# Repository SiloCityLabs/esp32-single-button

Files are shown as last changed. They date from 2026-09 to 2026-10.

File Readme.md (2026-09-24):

# ESP32 Single Button — battery keyfob (XIAO C3 / C6)

ESPHome firmware for a **single-button**, battery-powered remote on the same core circuit as [ESPFob](../espfob): one switch, WS2812B RGB with MOSFET power gating, and switched battery divider for low idle drain.

## Pin map (D silkscreen)

| D pin | Function | Notes |
| ----- | --- | --- |
| D0 | Battery sense  | 1:2 divider — multiply by 2 in YAML  |
| D1 | Button (SW1) | Deep-sleep wake (RTC / LP on C3 / C6) |
| D6 | RGB data | WS2812B |
| D9 | RGB power | HIGH = LED powered |
| D10 | Divider power  | HIGH = battery measurement enabled |

Button is active **low** (external 10k pull-up). On boot and each press, firmware briefly pulses the RGB LED, samples battery voltage, stays awake ~5s after each press (configurable via `awake_after_button_ms`), then deep sleeps until the next press.

## Files

| File | Target |
| --- | --- |
| `esphome-common.yaml` | Shared hardware / logic |
| `esphome-c6.yaml`  | Seeed XIAO **ESP32-C6** |
| `esphome-c3.yaml`  | Seeed XIAO **ESP32-C3** |

## Build and flash

```bash
make setup
make config-c6
make flash-c6
```

Factory images after `make build`: `firmware-c6.bin`, `firmware-c3.bin`.

Provisioning: Improv (BLE + serial) and captive portal fallback, same pattern as ESPFob.

## Home Assistant

Add the device via ESPHome Dashboard (open `esphome-c6.yaml` or clone this repo). Automate on the **Button** binary sensor entity.

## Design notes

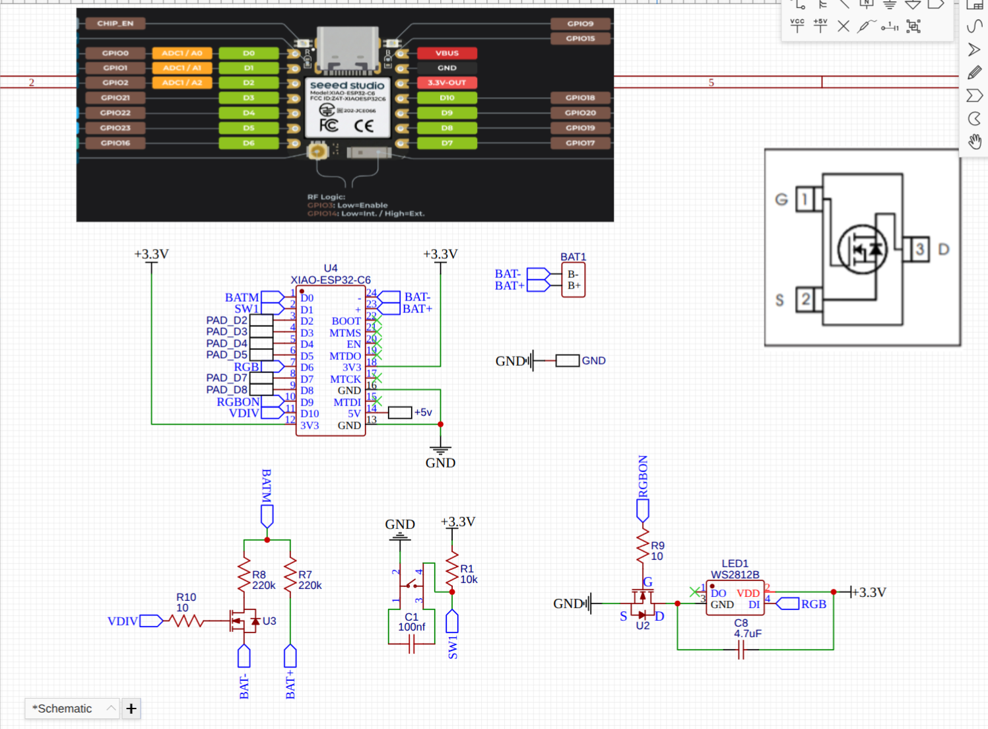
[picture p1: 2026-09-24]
images/schematic-rev1.png

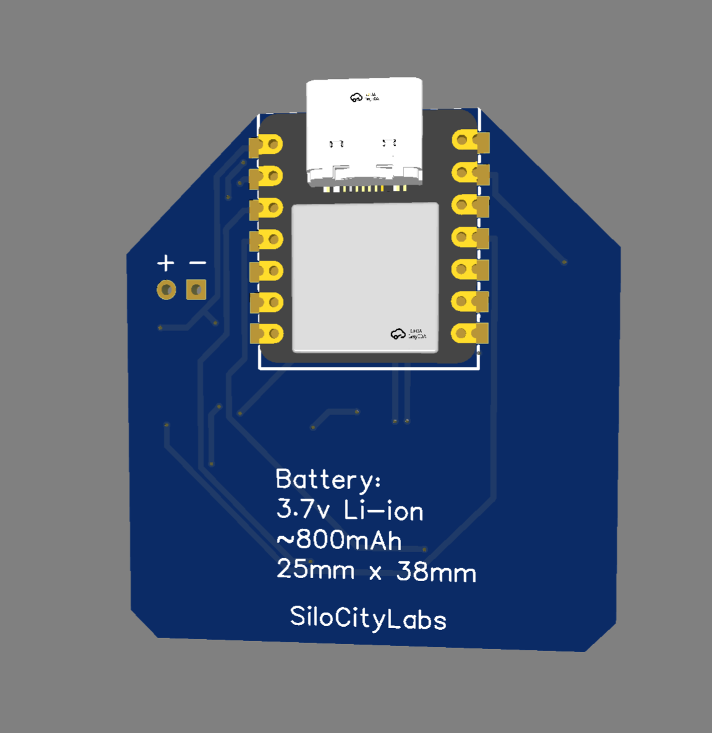
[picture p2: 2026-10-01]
images/pcb-rear-render-rev1.png

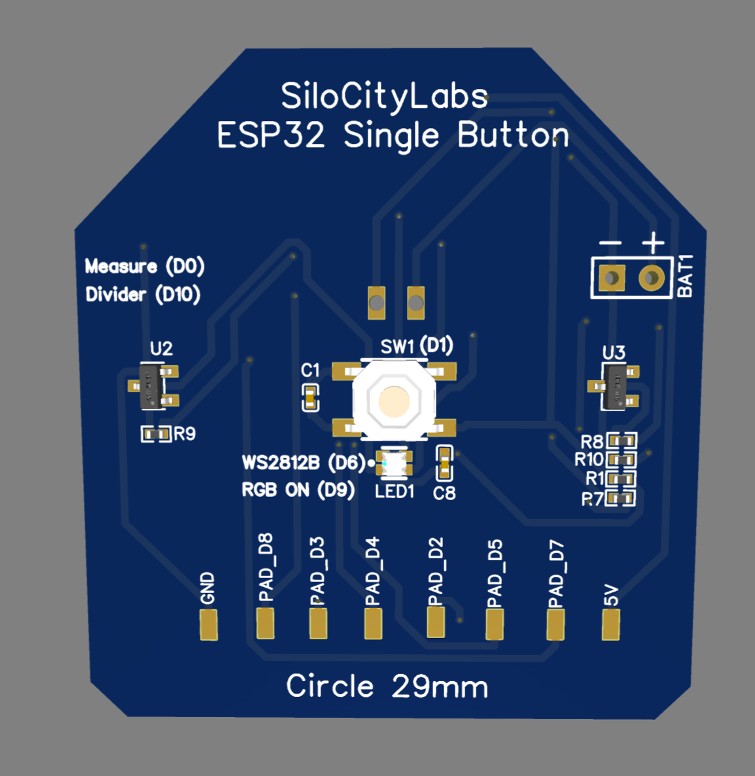
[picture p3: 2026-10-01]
images/pcb-front-render-rev1.png

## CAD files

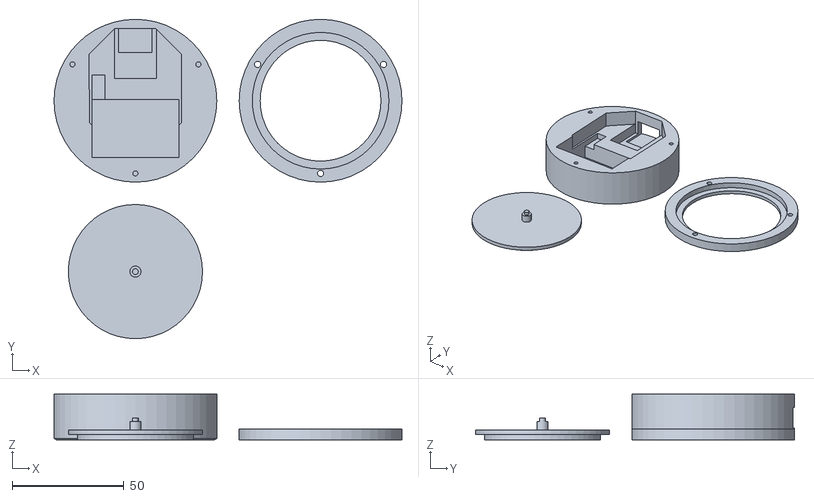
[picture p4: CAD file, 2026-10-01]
case/rev1/print.stl
155.6 x 142.8 x 20.3

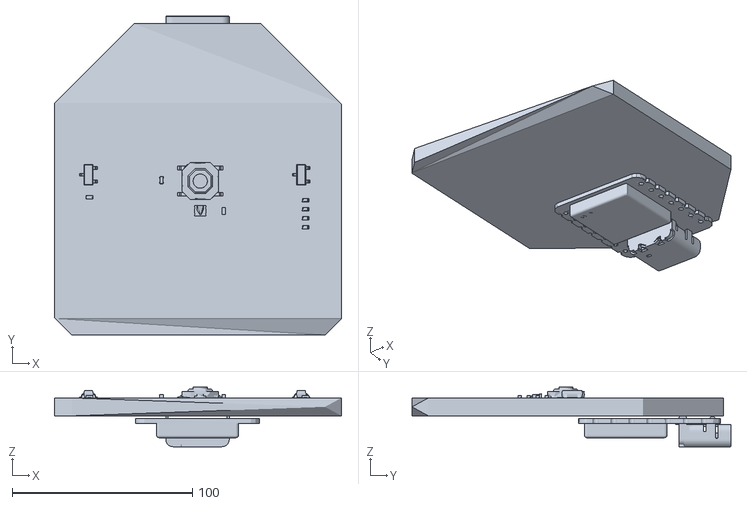
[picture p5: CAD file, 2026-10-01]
case/rev1/OBJ_PCB.obj
159.3 x 177.0 x 33.0

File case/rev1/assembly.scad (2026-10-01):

// Stacked preview. Not a printable part.
//   openscad -D 'cutaway=true' -o assembly.png assembly.scad
include <common.scad>
$fn = 48;

cutaway = false;
show_board = true;

module stacked() {
  color("white") base();
  color("ghostwhite") translate([0, 0, seat_z]) clamp();
  color("ivory") button_solid();
  if (show_board) {
    color("darkgreen", 0.35) pcb_ghost();
    color("dimgray", 0.4) xiao_ghost();
    color("olive", 0.4) battery_ghost();
  }
}

if (cutaway)
  difference() {
    stacked();
    translate([-80, 0, -5]) cube([80, 120, 80]);
  }
else
  stacked();

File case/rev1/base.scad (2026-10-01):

// Circular base. Print floor-down. No supports.
//   openscad -o base.stl base.scad
include <common.scad>
$fn = 64;

base();

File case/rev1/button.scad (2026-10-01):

// Center cap. Stem tip on the bed, flat face up.
// The flange is wider than the stem: turn on supports from the build plate only.
//   openscad -o button.stl button.scad
include <common.scad>
$fn = 64;

translate([0, 0, -tip_rest])
  button_solid();

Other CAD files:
case/rev1/clamp.scad
case/rev1/common.scad
case/rev1/print.scad

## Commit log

2026-10-01 some case work
    [OBJ_PCB.obj, assembly.scad, base.scad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]
2026-10-01 Smaller button
2026-10-08 More button case improvements
2026-10-09 more fine tunning of the case
2026-10-09 added button alignment
